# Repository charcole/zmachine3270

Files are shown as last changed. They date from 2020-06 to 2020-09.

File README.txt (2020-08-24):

ZMachine Interpreter for IBM 3270 compatible terminals
======================================================

Small dongle that provides Z-Machine interpreter (Infocom games), TN3270 (Telnet for 3270), SSH and Wikipedia clients.

Plugs into the serial port and uses SDLC and SNA networking protocols to communicate with the terminal over a 25-pin RS232 port.

Specificly this was designed for an Informer 270 376/SNA terminal.

There's a short video on YouTube at...
https://www.youtube.com/watch?v=U6nj1dibTCA

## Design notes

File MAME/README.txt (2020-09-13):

The included patch can be applied on top of MAME starting with ref 11782b47bd8fcc670ad259d7fe08de86a97f5eb5.

The driver is a mess as it was mainly just used for debugging the firmware and prototyping the network state machine so isn't possible to use as a terminal without quite a bit more work.

SDLC support was hacked in to the Z80 SIO driver and doesn't work exactly as it does in reality.

SoftDongle is a version of the ESP32 firmware that can run on a PC and be portable. Sends and recv data via network connection. Intended to feed into a future version of MAME.

BREAKING NEWS: Informer 207 376 support has been kindly implemented on the main branch of MAME by Dirk Best partly based on this code!

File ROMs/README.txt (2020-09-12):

ROM dumps from the system board:

- 79589-023.bin. An 8Kb M27128AF1 EPROM. It had a label "79589-032 376 SNAV1.00 201C E86F". On the PCB it's Z36.
- 79590-023.bin. A 16Kb M2764A F1 EPROM. It had a label "79690-023 376SNA V1.00 201C 7224". On the PCB it's Z37.
- chargen.bin is a TMS2732AGL-25 4Kb EPROM. It had a label "79573-001 V1.00 376/8 CHAR. GEN.". On the PCB it's designator isn't visible but I believe it's Z6.

combined.bin is the two numbered ROMs containing the firmware combined as they are laid out in memory.
combined.txt is the disassembly with a small number of notes added from the reverse engineering process.

No ownership is implied. Archived for research purposes. ROM contents: (C) Informer Computer Terminals

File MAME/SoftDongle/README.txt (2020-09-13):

Software version of dongle. Mostly a hack, need to unify with ESP32 code.

Sends and recieves data over the network. Could potentially be used to feed into MAME in the future.

WARNING: Untested code

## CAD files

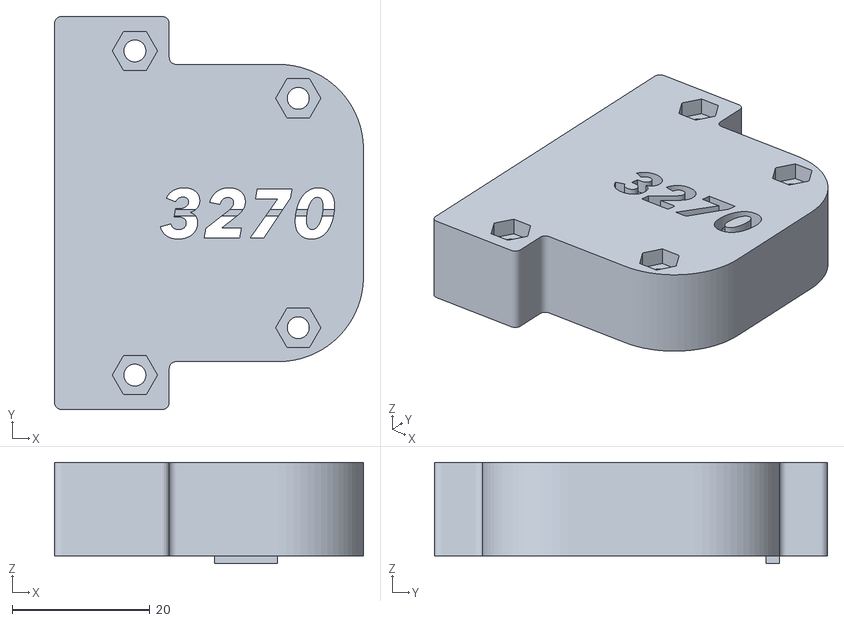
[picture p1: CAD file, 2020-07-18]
Fusion360/CaseTop.stl
44.8 x 57.0 x 14.7

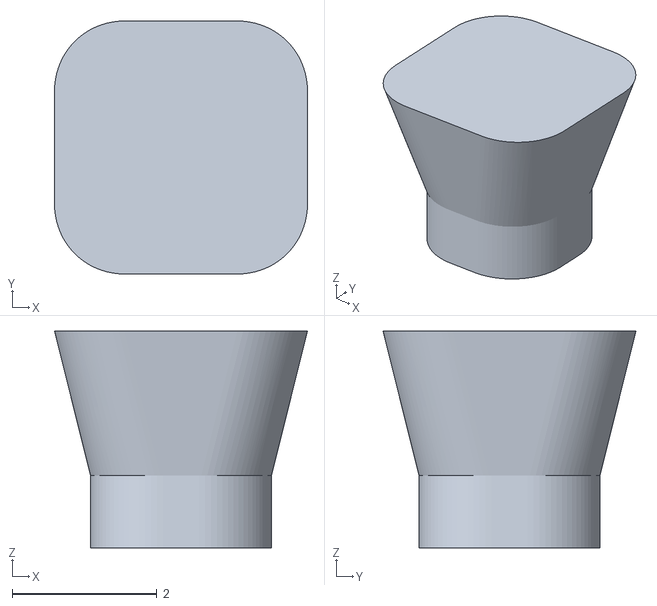
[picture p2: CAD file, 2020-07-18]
Fusion360/CaseButton.stl
3.50 x 3.50 x 3.00

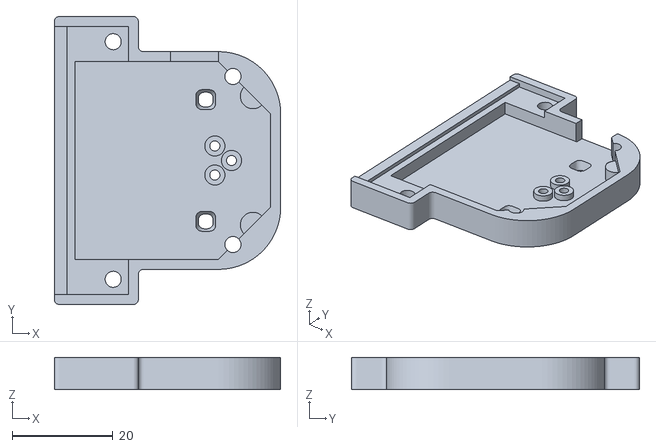
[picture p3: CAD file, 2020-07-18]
Fusion360/CaseBottom.stl
44.8 x 57.0 x 6.40

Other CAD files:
Fusion360/InformerCase.f3d

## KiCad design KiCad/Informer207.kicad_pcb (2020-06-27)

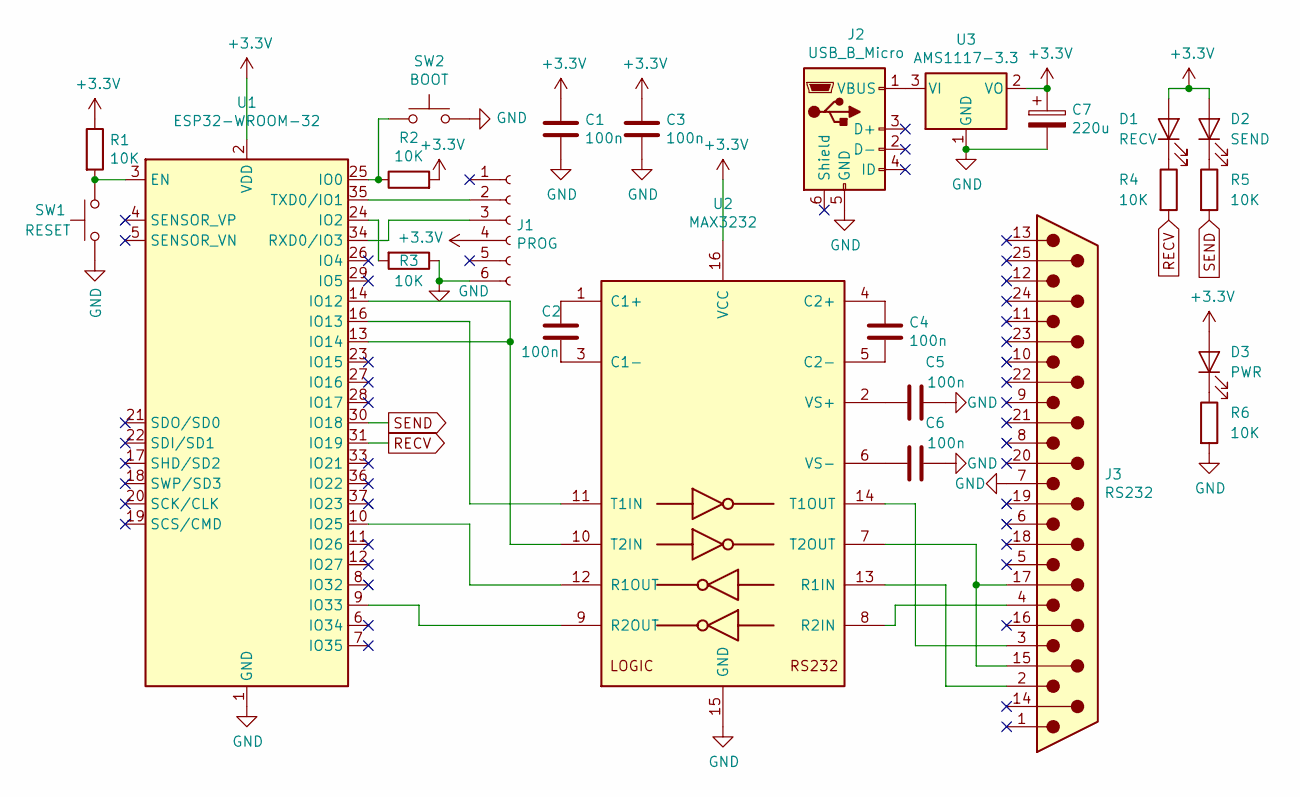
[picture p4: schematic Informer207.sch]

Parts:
C1, C2, C3, C4, C5, C6: 100n; C_1206_3216Metric_Pad1.42x1.75mm_HandSolder
C7: 220u; CP_EIA-6032-20_AVX-F_Pad2.25x2.35mm_HandSolder
D1: RECV; LED_1206_3216Metric_Pad1.42x1.75mm_HandSolder
D2: SEND; LED_1206_3216Metric_Pad1.42x1.75mm_HandSolder
D3: PWR; LED_1206_3216Metric_Pad1.42x1.75mm_HandSolder
J1: PROG; PinHeader_1x06_P2.54mm_Vertical
J2: USB_B_Micro; USB_Micro-B_Molex-105017-0001
J3: RS232; DSUB-25_Male_Horizontal_D25P13A4PL00LF
R1, R2, R3, R4, R5, R6: 10K; R_1206_3216Metric_Pad1.42x1.75mm_HandSolder
SW1: RESET; SW_SPST_CK_RS282G05A3
SW2: BOOT; SW_SPST_CK_RS282G05A3
U1: ESP32-WROOM-32
U2: MAX3232; SOIC-16_3.9x9.9mm_P1.27mm
U3: AMS1117-3.3; SOT-223-3_TabPin2

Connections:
+3V3: C1.1, C3.1, C7.1, D1.2 (A), D2.2 (A), D3.2 (A), J1.4, R1.1, R2.2, U1.2 (VDD), U2.16 (VCC), U3.2 (VO)
GND: C1.2, C3.2, C5.2, C6.2, C7.2, J1.6, J2.5 (GND), J3.7, R3.1, R6.2, SW1.1, SW2.2, U1.1 (GND), U1.15 (GND), U1.38 (GND), U2.15 (GND), U3.1 (GND)
unnamed: C2.1, U2.1 (C1+)
unnamed: C2.2, U2.3 (C1-)
unnamed: C4.1, U2.4 (C2+)
unnamed: C4.2, U2.5 (C2-)
unnamed: C5.1, U2.2 (VS+)
unnamed: C6.1, U2.6 (VS-)
unnamed: D1.1 (K), R4.1
unnamed: D2.1 (K), R5.1
unnamed: D3.1 (K), R6.1
unnamed: J1.2, U1.35 (TXD0/IO1)
unnamed: J1.3, U1.34 (RXD0/IO3)
unnamed: J2.1 (VBUS), U3.3 (VI)
unnamed: J3.2, U2.13 (R1IN)
unnamed: J3.3, U2.14 (T1OUT)
unnamed: J3.4, U2.8 (R2IN)
unnamed: J3.15, J3.17, U2.7 (T2OUT)
unnamed: R1.2, SW1.2, U1.3 (EN)
unnamed: R2.1, SW2.1, U1.25 (IO0)
unnamed: R3.2, U1.24 (IO2)
unnamed: U1.9 (IO33), U2.9 (R2OUT)
unnamed: U1.10 (IO25), U2.12 (R1OUT)
unnamed: U1.13 (IO14), U1.14 (IO12), U2.10 (T2IN)
unnamed: U1.16 (IO13), U2.11 (T1IN)
RECV: R4.2, U1.31 (IO19)
SEND: R5.2, U1.30 (IO18)

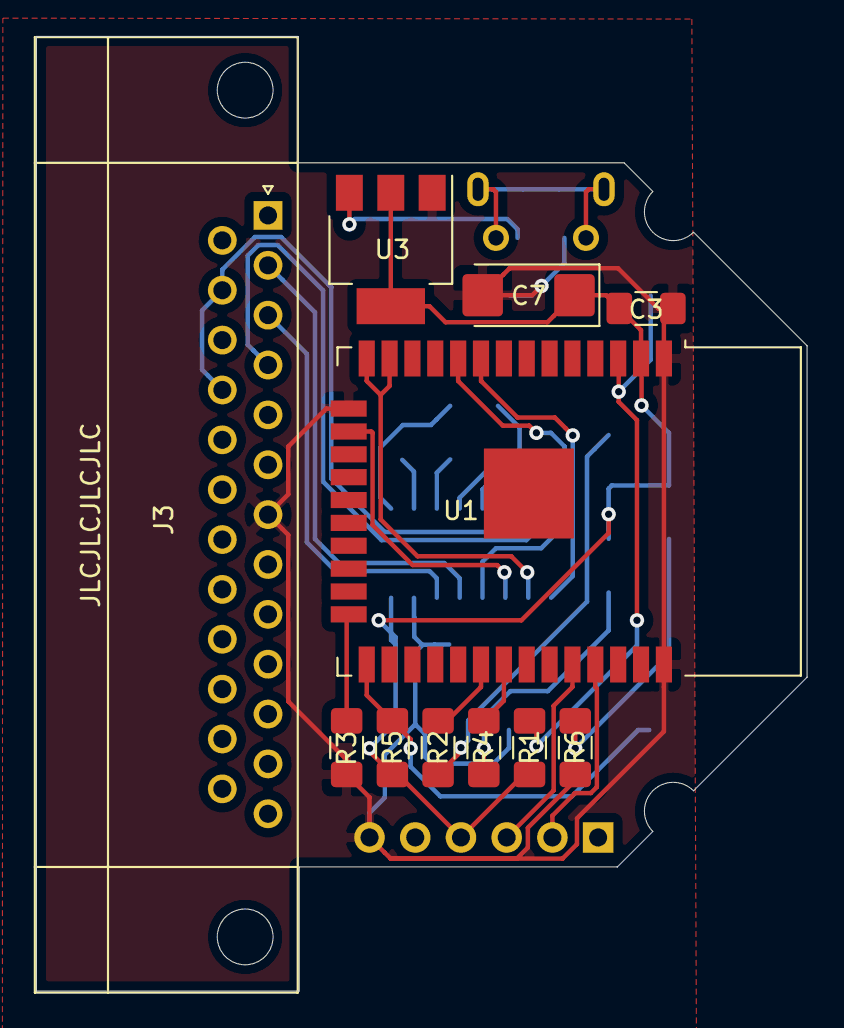
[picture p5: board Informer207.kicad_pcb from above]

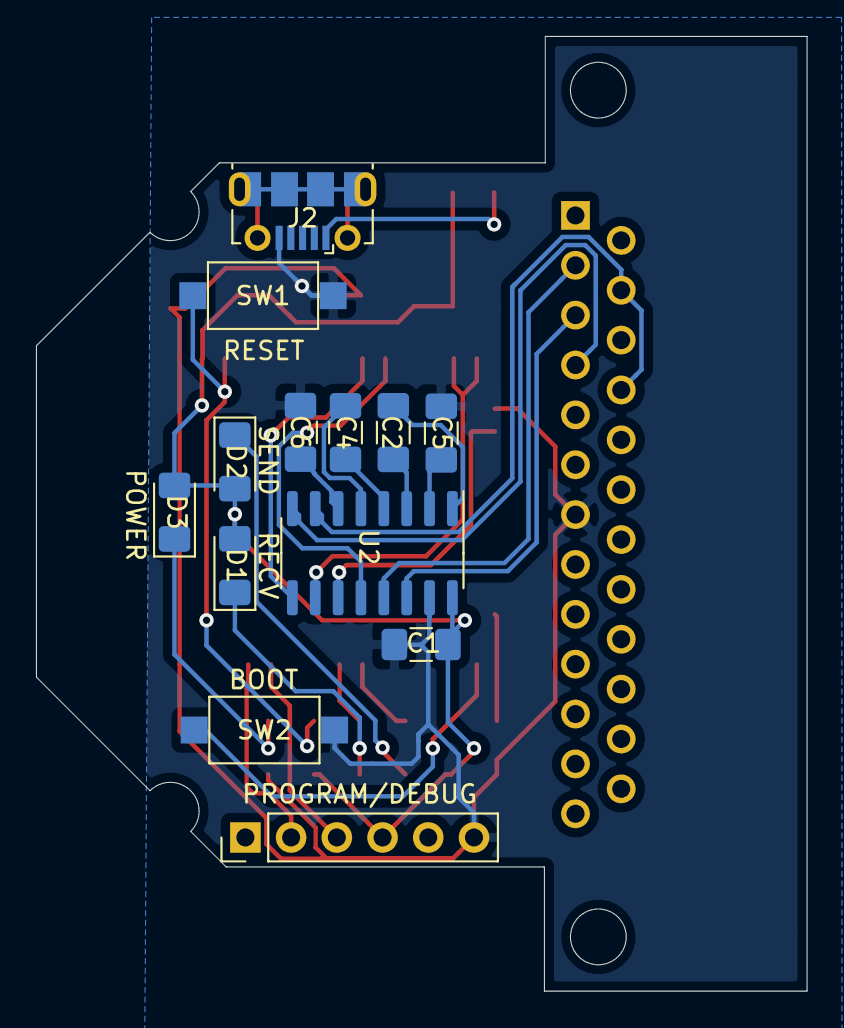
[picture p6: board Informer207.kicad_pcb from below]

Board: 2 copper layers, 42.8 x 53.0 mm, 24 parts (13 on the bottom side), 27 nets.

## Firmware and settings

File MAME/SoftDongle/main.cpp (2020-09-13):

#include "zops.h"
#include "FrontEnd.h"
#include "TN3270.h"
#include "crc.h"
#include "3270.h"
#include "Network.h"

#include <stdio.h>
#include <errno.h>
#include <stdlib.h>
#include <unistd.h>
#include <pthread.h>
#include <sys/time.h>
#include <sys/socket.h>
#include <netinet/in.h>
#include <arpa/inet.h>

#define DUMP_PACKETS 1

static NetworkState Network;

void* GameTask(void *Args)
{
	FrontEnd SelectionScreen;
	int CurrentGame = SelectionScreen.Show(&GScreen);
	while (CurrentGame < 0)
	{
		if (CurrentGame == -1)
		{
			TN3270::Run();
		}
		CurrentGame = SelectionScreen.Show(&GScreen);
	}
	FILE* f = fopen("game.z", "rb");
	if (!f)
	{
		printf("Couldn't find \"game.z\". Can be almost any Z3,Z4 or Z5 game. Quitting\n");
		return NULL;
	}
	fseek(f, 0, SEEK_END);
	int GameSize = ftell(f);
	fseek(f, 0, SEEK_SET);
	void* GameData = malloc(GameSize);
	fread(GameData, GameSize, 1, f);
	fclose(f);
	zopsMain((char*)GameData);
	free(GameData);
	return NULL;
}

class CBitStream
{
	public:
		CBitStream()
		{
			Reset();
		}

		CBitStream(const uint8_t* Data, int NumBytes)
		{
			memcpy(Bytes, Data, NumBytes);
			TotalBits = 8 * NumBytes;
			CurrentByte = NumBytes;
			CurrentMask = 1;
		}

		void Reset()
		{
			TotalBits = 0;
			CurrentByte = 0;
			CurrentMask = 1;
			Bytes[CurrentByte] = 0;
		}

		void Flush()
		{
			// Ready for reading
			CurrentByte = 0;
			CurrentMask = 1;
		}

		bool Finished() const
		{
			return TotalBits == 0;
		}

		bool ReadBit()
		{
			bool bBit = ((Bytes[CurrentByte] & CurrentMask) != 0);
			TotalBits--;
			if (CurrentMask == 0x80)
			{
				CurrentMask = 1;
				CurrentByte++;
			}
			else
			{
				CurrentMask <<= 1;
			}
			return bBit;
		}

		void WriteBit(bool bBit)
		{
			if (bBit)
			{
				Bytes[CurrentByte] |= CurrentMask;
			}
			TotalBits++;
			if (CurrentMask == 0x80)
			{
				CurrentMask = 1;
				CurrentByte++;
				Bytes[CurrentByte] = 0;
			}
			else
			{
				CurrentMask <<= 1;
			}
		}

		const uint8_t* ToBytes(int& NumBits)
		{
			NumBits = TotalBits;
			return Bytes;
		}

	private:
		enum
		{
			MAX_MESSAGE_LENGTH = (2048+1024)
		};

		int32_t TotalBits;
		int32_t CurrentByte;
		uint8_t CurrentMask;
		uint8_t Bytes[MAX_MESSAGE_LENGTH];
};

void InsertFlags(CBitStream& Dest)
{
	Dest.WriteBit(0);
	Dest.WriteBit(1);
	Dest.WriteBit(1);
	Dest.WriteBit(1);
	Dest.WriteBit(1);
	Dest.WriteBit(1);
	Dest.WriteBit(1);
	Dest.WriteBit(0);
}

void CalculateCRC(CBitStream& Dest, CBitStream& Source)
{
	uint16_t CRC = 0xFFFF;

	Dest.Reset();
	while (!Source.Finished())
	{
		uint16_t bData = (Source.ReadBit() ? 1: 0);
		uint16_t bLastBit = (CRC >> 15);
		uint16_t bDataBit = (bData ^ bLastBit);
		CRC = bDataBit + (CRC << 1);
		if (bDataBit)
		{
			CRC ^= (1<<5) + (1<<12);
		}
		Dest.WriteBit(bData);
	}
	for (int BitIndex = 0; BitIndex < 16; BitIndex++)
	{
		Dest.WriteBit(!(CRC >> 15));
		CRC <<= 1;
	}
	Dest.Flush();
}

void ZeroBitAndFlagInsertion(CBitStream& Dest, CBitStream& Source)
{
	uint8_t NumBits = 0;

	Dest.Reset();
	InsertFlags(Dest);
	while (!Source.Finished())
	{
		bool bData = Source.ReadBit();
		Dest.WriteBit(bData);
		if (bData)
		{
			NumBits++;
			if (NumBits == 5)
			{
				Dest.WriteBit(0);
				NumBits = 0;
			}
		}
		else
		{
			NumBits = 0;
		}
	}
	InsertFlags(Dest);
	Dest.Flush();
}

int CurrentPacketByte = 0x80;
int CurrentPacketIndex = 0;
uint8_t PacketData[4096];
int RunCount = 0;

bool RecvBit(bool bBit)
{
	if (bBit)
	{
		RunCount++;
	}
	else
	{
		int RunLength = RunCount;
		RunCount = 0;

		if (RunLength >= 6)
		{
			CurrentPacketByte = 0x80;
			CurrentPacketIndex = 0;
			return (RunLength == 6);
		}
		else if (RunLength >= 5)
		{
			// If 5 then needs to be dropped
			return false;
		}
	}

	bool bFlush = ((CurrentPacketByte & 1) != 0);
	CurrentPacketByte >>= 1;
	CurrentPacketByte |= (bBit ? 0x80 : 0);
	if (bFlush)
	{
		if (CurrentPacketIndex < sizeof(PacketData))
		{
			PacketData[CurrentPacketIndex] = CurrentPacketByte;
		}
		CurrentPacketIndex++;
		CurrentPacketByte = 0x80;
	}
	return false;
}

int main(int argc, char** argv)
{
	if (argc != 3)
	{
		printf("Usage 3270.out ip_addr port\n");
		return 1;
	}

	int Socket = socket(PF_INET, SOCK_STREAM, IPPROTO_TCP);
    if (Socket == -1)
    {
        printf("Failed to create socket\n");
        return 1;
    }

	int port = atoi(argv[2]);
	printf("Connecting to %s:%d\n", argv[1], port);

    struct sockaddr_in DestAddr;
    DestAddr.sin_addr.s_addr = inet_addr(argv[1]);
    DestAddr.sin_family = AF_INET;
    DestAddr.sin_port = htons(port);

    if (connect(Socket, (struct sockaddr *)&DestAddr, sizeof(DestAddr)) == -1)
    {
        close(Socket);
        printf("Failed to connect socket\n");
        return 1;
    }

	BuildCRCLookup();
	BuildTextTables();

	pthread_t GameThread;
	void *Ret;
	pthread_create(&GameThread, NULL, GameTask, NULL);

	while (true)
	{
		uint8_t SendBuffer[2048+1024];
		bool bWaitForReply = false;
		int SendSize = Network.GenerateNewPackets(SendBuffer, bWaitForReply);

#if DUMP_PACKETS
		printf("Sending packet of size %d:", SendSize);
		for (int i=0; i<SendSize; i++)
		{
			printf(" %02x", SendBuffer[i]);
		}
		printf("\n");
#endif

		CBitStream A(SendBuffer, SendSize);
		CBitStream B;

		A.Flush();
		CalculateCRC(B, A);
		ZeroBitAndFlagInsertion(A, B);

		int NumBitsToSend = 0;
		const uint8_t* BytesToSend = A.ToBytes(NumBitsToSend);
		send(Socket, BytesToSend, (NumBitsToSend+7)/8, 0);

		fd_set RecvFdSet;
		FD_ZERO(&RecvFdSet);
		FD_SET(Socket, &RecvFdSet);
		timeval TimeVal;
		TimeVal.tv_sec=1;
		TimeVal.tv_usec=0;
		int SelectReturn = select(Socket + 1, &RecvFdSet, nullptr, nullptr, &TimeVal);
		if (SelectReturn > 0 && FD_ISSET(Socket, &RecvFdSet))
		{
			uint8_t RX[2048];
			int NumRX = recv(Socket, RX, sizeof(RX), 0);
			if (NumRX == 0)
			{
				printf("recv returned zero. Connection closed?\n");
				return 1;
			}
			else if (NumRX < 0)
			{
				printf("recv error: %d errno:%d\n", NumRX, errno);
				return 1;
			}
			CBitStream ReceivedBits(RX, NumRX);
			while (!ReceivedBits.Finished())
			{
				bool Bit = ReceivedBits.ReadBit();
				int LengthOfPacket = CurrentPacketIndex;
				if (RecvBit(Bit))
				{
					if (LengthOfPacket < sizeof(PacketData))
					{
#if DUMP_PACKETS
						printf("Recieved packet of length %d:", LengthOfPacket);
						for (int i=0; i<LengthOfPacket; i++)
						{
							printf(" %02x", PacketData[i]);
						}
						printf("\n");
#endif

						PacketParser ProcessedPacket;
						ProcessedPacket.Parse(PacketData, LengthOfPacket);
#if DUMP_PACKETS
						ProcessedPacket.Dump(PacketData);
#endif
						Network.ProcessPacket(ProcessedPacket, PacketData);
					}
					else
					{
						printf("Packet over max length %d :(\n", LengthOfPacket);
					}
				}
			}
		}
	}

	pthread_join(GameThread, &Ret);
        
	close(Socket);

	return 0;
}

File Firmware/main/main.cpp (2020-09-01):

// (c) Charlie Cole 2018

#include <stdio.h>
#include <math.h>
#include <string.h>
#include <algorithm>
extern "C"
{
#include "freertos/FreeRTOS.h"
#include "freertos/task.h"
#include "freertos/event_groups.h"
#include "nvs_flash.h"
#include "esp_system.h"
#include "esp_wifi.h"
#include "esp_event_loop.h"
#include "esp_log.h"
#include "lwip/err.h"
#include "lwip/sys.h"
#include "lwip/sockets.h"
#include "esp_ota_ops.h"
#include "esp_http_client.h"
#include "esp_vfs.h"
#include "esp_vfs_fat.h"
};
#include "webpage.h"
#include "zops.h"
#include "FrontEnd.h"
#include "TN3270.h"
#include "Wikipedia.h"
#include "SSH.h"

#ifndef CONFIG_WL_SECTOR_SIZE
#define CONFIG_WL_SECTOR_SIZE 4096
#endif

#define ARRAY_NUM(x) (sizeof(x)/sizeof(x[0]))

#define EXAMPLE_ESP_WIFI_SSID      "TALKTALK4153C8_24Ghz"
#define EXAMPLE_ESP_WIFI_PASS      "EX4T6H46"

#define STORAGE_NAMESPACE "settingsns"

#define TOTAL_GAME_FLASH_SIZE		(768*1024)

/* FreeRTOS event group to signal when we are connected*/
static EventGroupHandle_t wifi_event_group;

static wl_handle_t s_wl_handle = WL_INVALID_HANDLE;

struct Configuration
{
	int32_t Dummy;
};

Configuration Config;
		
volatile bool bQuitTasks = false;
volatile bool bDoneQuitTask1 = false;
volatile bool bDoneQuitTask2 = false;

extern void CreateSendRecieveTasks();

static void ClearSettings()
{
	Config =
	{
		0
	};
}

static esp_err_t LoadSettings(void)
{
	nvs_handle my_handle;
	esp_err_t err;
				
	err = nvs_open(STORAGE_NAMESPACE, NVS_READONLY, &my_handle);
	printf("Opening namespace %d\n", err);
	if (err == ESP_OK)
	{
		size_t required_size = 0;
		err = nvs_get_blob(my_handle, "settings", NULL, &required_size);
		printf("Get blob %d %d\n", err, required_size);
		
		if (err == ESP_OK && required_size == sizeof(Config))
		{
			err = nvs_get_blob(my_handle, "settings", &Config, &required_size);
			printf("Get blob(2) %d %d\n", err, required_size);
		}

		nvs_close(my_handle);
	}

	return err;
}

static esp_err_t SaveSettings(void)
{
	nvs_handle my_handle;
	esp_err_t err;

	err = nvs_open(STORAGE_NAMESPACE, NVS_READWRITE, &my_handle);
	printf("Opening namespace %d\n", err);
	if (err == ESP_OK)
	{
		err = nvs_set_blob(my_handle, "settings", &Config, sizeof(Config));
		printf("Set blob %d\n", err);

		if (err == ESP_OK)
		{
			err = nvs_commit(my_handle);
			printf("Commit %d\n", err);
		}

		nvs_close(my_handle);
	}

	return err;
}

void WifiStartListening(void *pvParameters)
{
	static char WifiBuffer[2048];
	static char OutBuffer[4096];
	int Sock = socket(PF_INET, SOCK_STREAM, 0);
	
	sockaddr_in SockAddrIn;	
	memset(&SockAddrIn, 0, sizeof(SockAddrIn));
	SockAddrIn.sin_family = AF_INET;
	SockAddrIn.sin_port = htons(80);
	SockAddrIn.sin_addr.s_addr = htonl(INADDR_ANY);
	bind(Sock, (struct sockaddr *)&SockAddrIn, sizeof(SockAddrIn));
	
	listen(Sock, 5);

	bool bUpdated = false;
	while (!bUpdated)
	{
		sockaddr_in ClientSockAddrIn;
		socklen_t ClientSockAddrLen = sizeof(ClientSockAddrIn);
		int ClientSock = accept(Sock, (sockaddr*)&ClientSockAddrIn, &ClientSockAddrLen);
	
		if (ClientSock != -1)
		{
			int Recieved = recv(ClientSock, &WifiBuffer, sizeof(WifiBuffer) - 1, 0);
			if (Recieved > 0)
			{
				WifiBuffer[Recieved] = 0;

				const char* ExpectedRequests[] =
				{
					"GET /",
					"POST / HTTP/",
					"POST /index.html HTTP/",
					"POST /game.html HTTP/"
				};

				bool bReturnIndex = false;
				bool bStartRecieving = false;
				bool bUploadingGame = false;
				ESP_LOGI("ota", "got:%s", WifiBuffer);
				for (int i = 0; i < ARRAY_NUM(ExpectedRequests); i++)
				{
					ESP_LOGI("ota", "testing:%s", ExpectedRequests[i]);
					int Len = strlen(ExpectedRequests[i]);
					if (Recieved >= Len && strncmp(WifiBuffer, ExpectedRequests[i], Len) == 0)
					{
						ESP_LOGI("ota", "matched:%s", ExpectedRequests[i]);
						if (strncmp(WifiBuffer, "POST", 4) == 0)
						{
							bStartRecieving = true;
							bUploadingGame = (i == 3);
						}
						else
						{
							bReturnIndex = true;
						}
						break;
					}
				}

				if (bStartRecieving)
				{
					bQuitTasks = true;
					while (!bDoneQuitTask1)
					{
						vTaskDelay(10);
					}
					while (!bDoneQuitTask2)
					{
						vTaskDelay(10);
					}

					int Length = 0;
					const char* ContentLength = strstr(WifiBuffer, "Content-Length: ");
					if (ContentLength)
					{
						Length = atoi(ContentLength + strlen("Content-Length: "));
					}

					esp_err_t ErrorCode = ESP_OK;
					bool bWaitingForStart = true;
					esp_ota_handle_t UpdateHandle = 0 ;
					const esp_partition_t *UpdatePartition = nullptr;
					
					if (bUploadingGame)
					{
						UpdatePartition = esp_partition_find_first(ESP_PARTITION_TYPE_DATA, (esp_partition_subtype_t)0x40, "games");
					}
					else
					{
					 	UpdatePartition = esp_ota_get_next_update_partition(nullptr);
					}
					
					ESP_LOGI("ota", "partition:%p", UpdatePartition);

					if (UpdatePartition && Length > 0)
					{
						size_t UploadOffset = 0;
						while (Length > 0)
						{
							Recieved = recv(ClientSock, &WifiBuffer, sizeof(WifiBuffer) - 1, 0);
							if (Recieved <= 0)
								break;

							WifiBuffer[Recieved] = 0;
							if (bWaitingForStart)
							{
								const char *Start = strstr(WifiBuffer, bUploadingGame?"LGV_DATA":"LGV_FIRM");
								if (Start)
								{
									bWaitingForStart = false;
									if (bUploadingGame) // Erase flash
									{
										ErrorCode = esp_partition_erase_range(UpdatePartition, 0, TOTAL_GAME_FLASH_SIZE);
									}
									else
									{
										ErrorCode = esp_ota_begin(UpdatePartition, OTA_SIZE_UNKNOWN, &UpdateHandle);
									}
									ESP_LOGI("ota", "ota begin:%d", ErrorCode);
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

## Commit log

2020-06-10 ESP32 program template (simplified version of train clock)
2020-06-21 Reduced zops memory footprint
2020-06-25 Verified correct SPI mode / edge trigger
    [LowLevel.cpp]
2020-06-27 First pass PCB design
    [Informer207.kicad_pcb, Informer207.sch]
2020-06-27 Added possible Ready To Recieve line (some activity on it)
    [Informer207.kicad_pcb, Informer207.sch]
2020-06-27 PCB order gerbers
    [Informer207-B_Cu.gbr, Informer207-B_Mask.gbr, Informer207-B_SilkS.gbr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]
2020-06-28 Save and restore (untested)
    [partitions.csv]
2020-06-28 Fixes for saving/restoring
    [partitions.csv]
2020-07-01 Game from partition
    [partitions.csv]
2020-07-02 Make multiple games available
    [partitions.csv]
2020-07-03 Chaining and flow control
2020-07-15 Reduce SSH memory usage (had broken Wiki)
    [libssh2_priv.h]
2020-07-18 3D printed case for PCB
    [CaseBottom.stl, CaseButton.stl, CaseTop.stl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]
2020-07-29 Fix for Trinity crash, out of range mem stream
    [zops.c]
2020-07-30 Missing input from version 4+ integrate
    [zops.c]
2020-08-01 Extended mappings (sadly no square brackets)
2020-08-01 Add secret fourth game for testing bigger games
    [partitions.csv]
2020-08-02 Change game selection
    [partitions.csv]
2020-08-05 print_addr and random sign fixes
    [zops.c]
2020-09-09 Add the PCB designators
